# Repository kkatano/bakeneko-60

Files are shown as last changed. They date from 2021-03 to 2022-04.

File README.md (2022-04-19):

# Bakeneko 60 V3

A simple 60% keyboard for DIYers. This project is a special homage to TGR x Singa UNIKORN 60 and OTD 356 Mini. See also the [introduction video](https://youtu.be/8zyG34YU3BY).

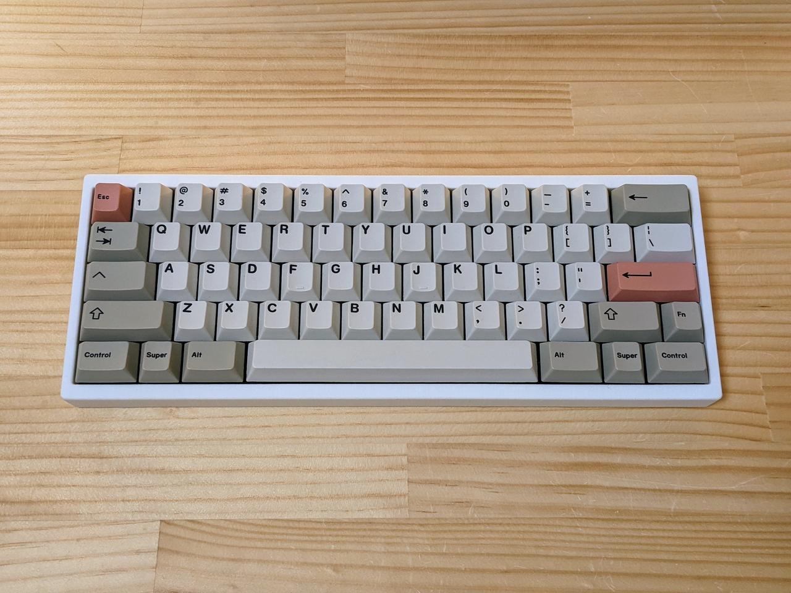
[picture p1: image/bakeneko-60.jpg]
Bakeneko 60


## Features

- Single piece tray case
- O-ring gasket mount (Friction fit)
- [Unified Daughterboard](https://github.com/ai03-2725/Unified-Daughterboard)
- QMK firmware and VIA
- Compatible with common 60% plates
- PCB designed with KiCAD 5.1.4

## Layouts

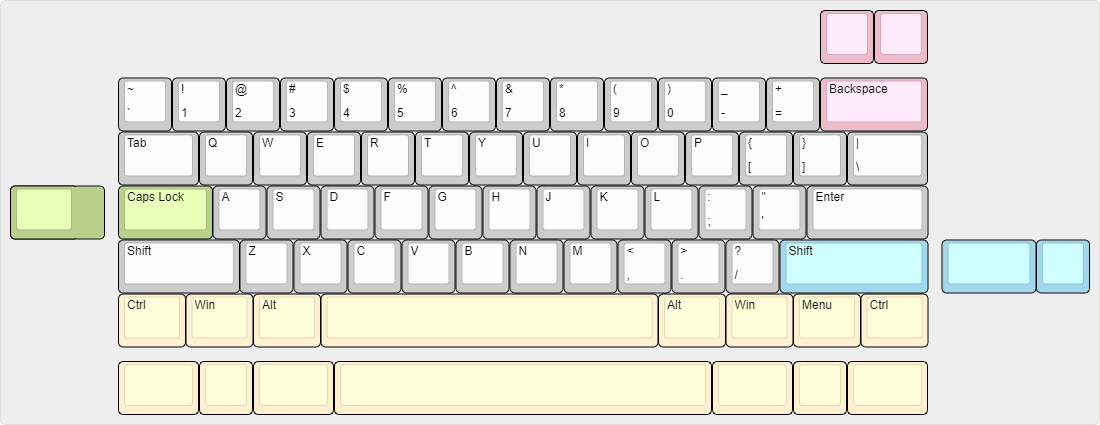
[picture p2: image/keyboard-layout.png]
Bakeneko 60 layouts


## Specs

- Dimensions: 295 x 110 x 30mm
- Front height: 18.5mm
- Home row height: 31mm(with GMK keycaps and bumpons)
- Typing angle: 6 degree
- Weight:
  - PLA Case: 370g
  - Aluminum Case: 700g
- O-ring gasket: VMQ-50(Silicone 50 duro) AS568-262

## Notes

- Old files (v1) are no longer available. See [geekhack post](https://geekhack.org/index.php?topic=107316.msg2974824#msg2974824) for the context
- The use of old (v1) mounting posts is prohibited
- All files are to be used at your own risk
- As for stabilizers, only PCB snap ins are supported
- This open source version is not compatible with CannonKeys Bakeneko

## Resources

- Documents: https://drive.google.com/drive/folders/1tddSihOS8Pgf1lTQOjHohYCl8efxXIeH
  - Parts guide and other useful information
  - Will be added and updated as needed
- Discord: https://discord.gg/fMY96TeEwV
  - Have fun with community members
  - Talk about Bakeneko builds and mods, and share your works
  - You can also contact me from there

## Special thanks to

- **Elaine** for [Unikorn](https://geekhack.org/index.php?topic=98587.50). Allowed me to publish the Unikorn-inspired case as open source and encouraged me
- Of course, I also show my respect and gratitude to **yuktsi**
- **coarse** for PCB review and kind support. His great work has refined the PCB well

## Also I should mention

- **OTD** for 356 Mini. Origin of O-ring gasket mount style
- **Evy** for [Plain60 series](https://github.com/evyd13/plain60-c). I used it as a reference for my PCB design. They also answered my miscellaneous questions
- **ai03** for [MX_Alps_Hybrid](https://github.com/ai03-2725/MX_Alps_Hybrid). Also got a lot of help from his discord server
- **overset** for [JP01](https://github.com/overset/JP01). The idea of publishing the case design on Onshape. After seeing their great work I switched from fusion360 to Onshape
- **Rhuk** gave me a lot of advice on keyboard design and manufacturing
- **Maker Keyboards** suggested adding a plate cutout to remove the PCB using a keycap puller
- And many community members for giving me advice and feedback, thanks!

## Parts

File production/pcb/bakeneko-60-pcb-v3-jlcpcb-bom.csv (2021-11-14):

Designator | Comment | Footprint | LCSC Part #
C1 C2 C3 | 0.1u | Capacitor_SMD:C_0805_2012Metric | C49678
C4 | 10u | Capacitor_SMD:C_0805_2012Metric | C15850
C5 C7 | 22p | Capacitor_SMD:C_0805_2012Metric | C1804
C6 | 1u | Capacitor_SMD:C_0805_2012Metric | C28323
D63 D62 D61 D60 D59 D58 D57 D56 D55 D54 D53 D52 D51 D50 D49 D48 D47 D46 D45 D44 D43 D42 D41 D40 D39 D38 D37 D36 D35 D34 D33 D32 D31 D30 D29 D28 D27 D26 D25 D24 D23 D22 D21 D20 D19 D18 D17 D16 D15 D14 D13 D12 D11 D10 D9 D8 D7 D6 D5 D4 D3 D2 D1 | 1N4148 | Diode_SMD:D_SOD-123 | C81598
F1 | 500mA | Fuse:Fuse_1206_3216Metric | C70076
J1 | JST SH 4-pin | Connector_JST:JST_SH_SM04B-SRSS-TB_1x04-1MP_P1.00mm_Horizontal | C160404
R1 R2 | 22 | Resistor_SMD:R_0805_2012Metric | C17561
R4 R3 | 10k | Resistor_SMD:R_0805_2012Metric | C17414
SW1 | Reset | Button_Switch_SMD:SW_SPST_TL3342 | C318884
U1 | SRV05-4 | Package_TO_SOT_SMD:SOT-23-6 | C85364
U2 | ATmega32U4-AU | Package_QFP:TQFP-44_10x10mm_P0.8mm | C44854
Y1 | 16MHz | Crystal:Crystal_SMD_3225-4Pin_3.2x2.5mm | C13738

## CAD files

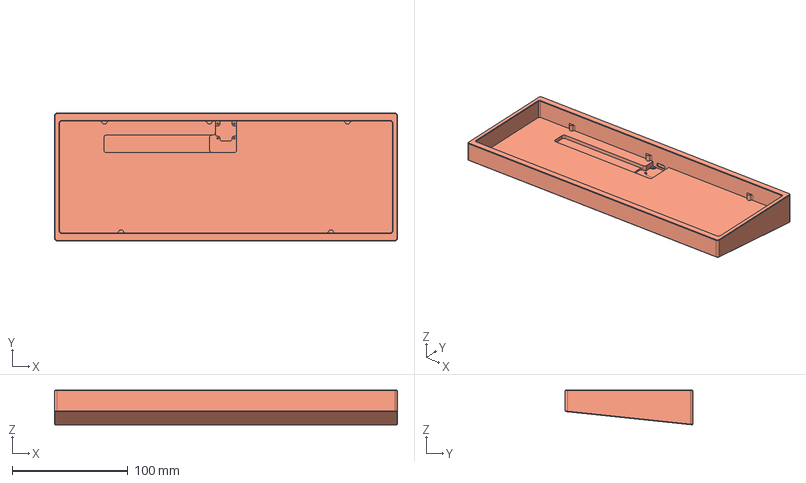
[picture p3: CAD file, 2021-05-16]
case-pla/bakeneko-60-pla.step
295.7 x 110.2 x 30.0 mm

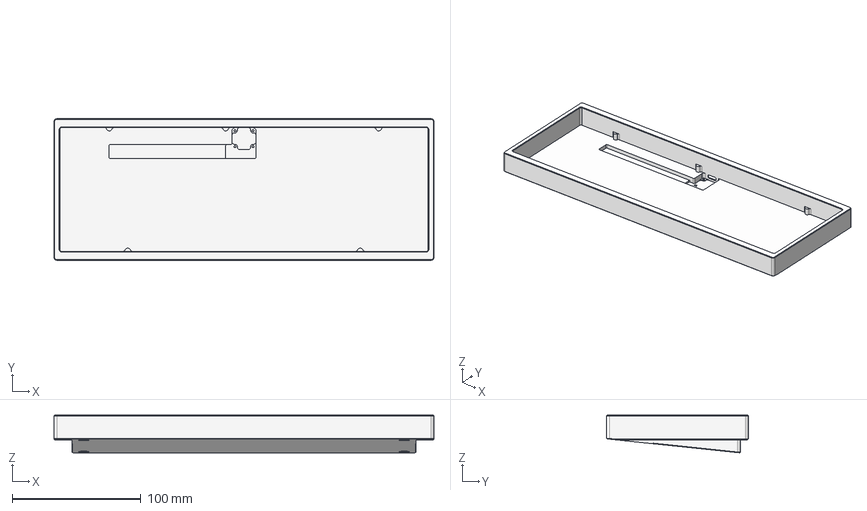
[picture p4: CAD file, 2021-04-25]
case/aluminum/bakeneko-60-case.step
295.7 x 110.2 x 29.4 mm

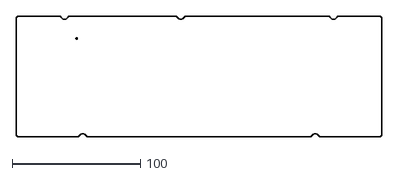
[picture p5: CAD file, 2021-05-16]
pcb/pcb-outline.dxf
284.7 x 94.2

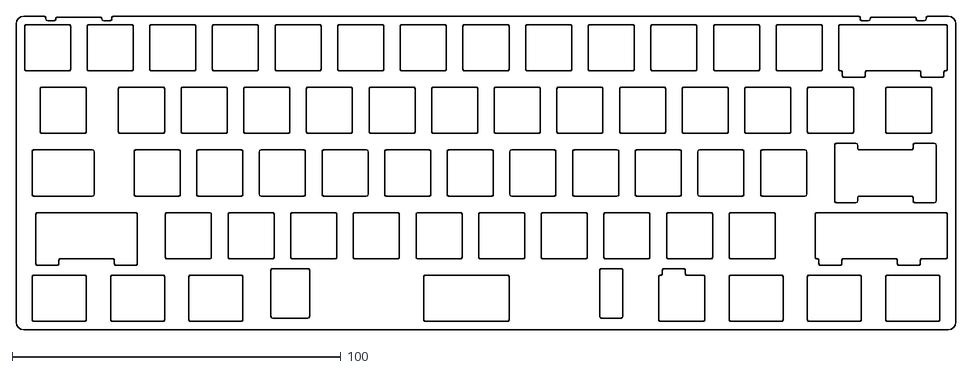
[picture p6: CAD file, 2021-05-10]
plate/bakeneko-60-plate.dxf
285.8 x 95.3

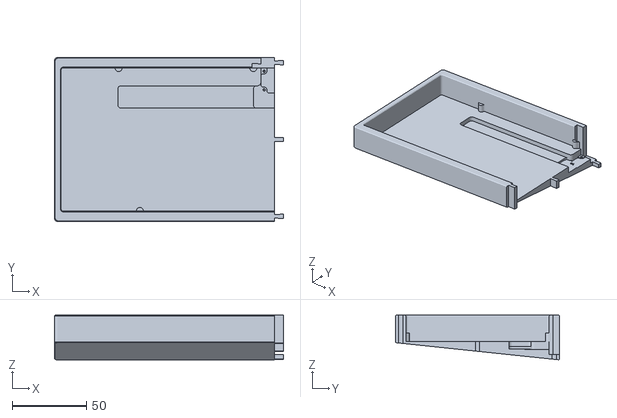
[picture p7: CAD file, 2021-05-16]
case-pla/bakeneko-60-pla-split-left.stl
153.9 x 110.2 x 30.0

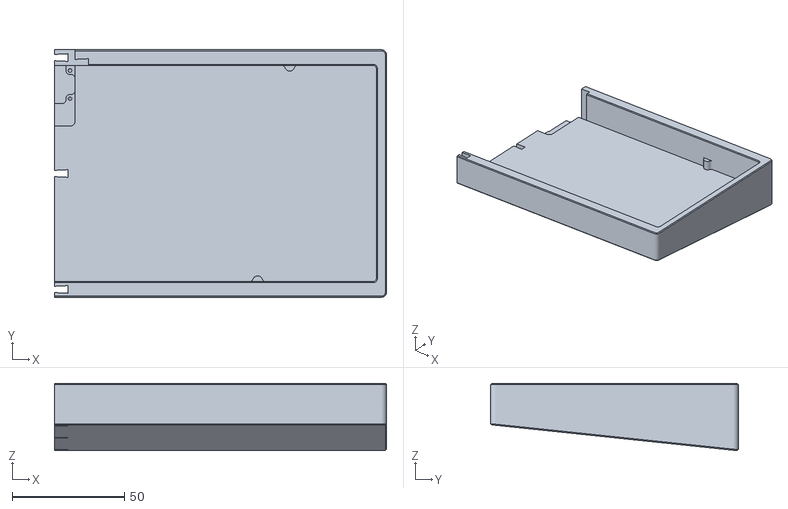
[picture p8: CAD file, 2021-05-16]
case-pla/bakeneko-60-pla-split-right.stl
147.8 x 110.2 x 30.0

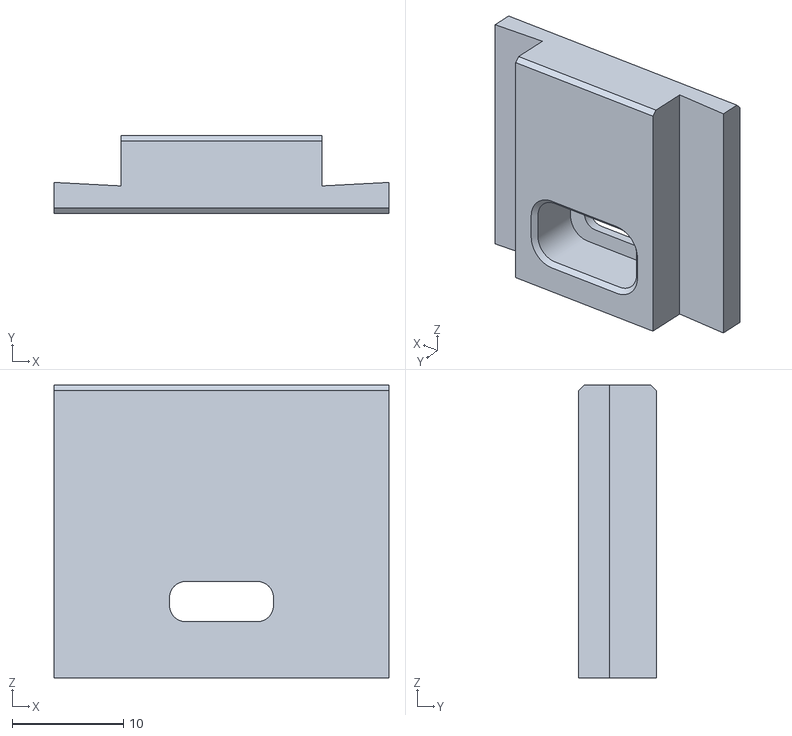
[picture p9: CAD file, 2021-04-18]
case-pla/bakeneko-60-pla-split-usb.stl
30.1 x 7.00 x 26.3

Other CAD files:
case/bakeneko-60-case.step

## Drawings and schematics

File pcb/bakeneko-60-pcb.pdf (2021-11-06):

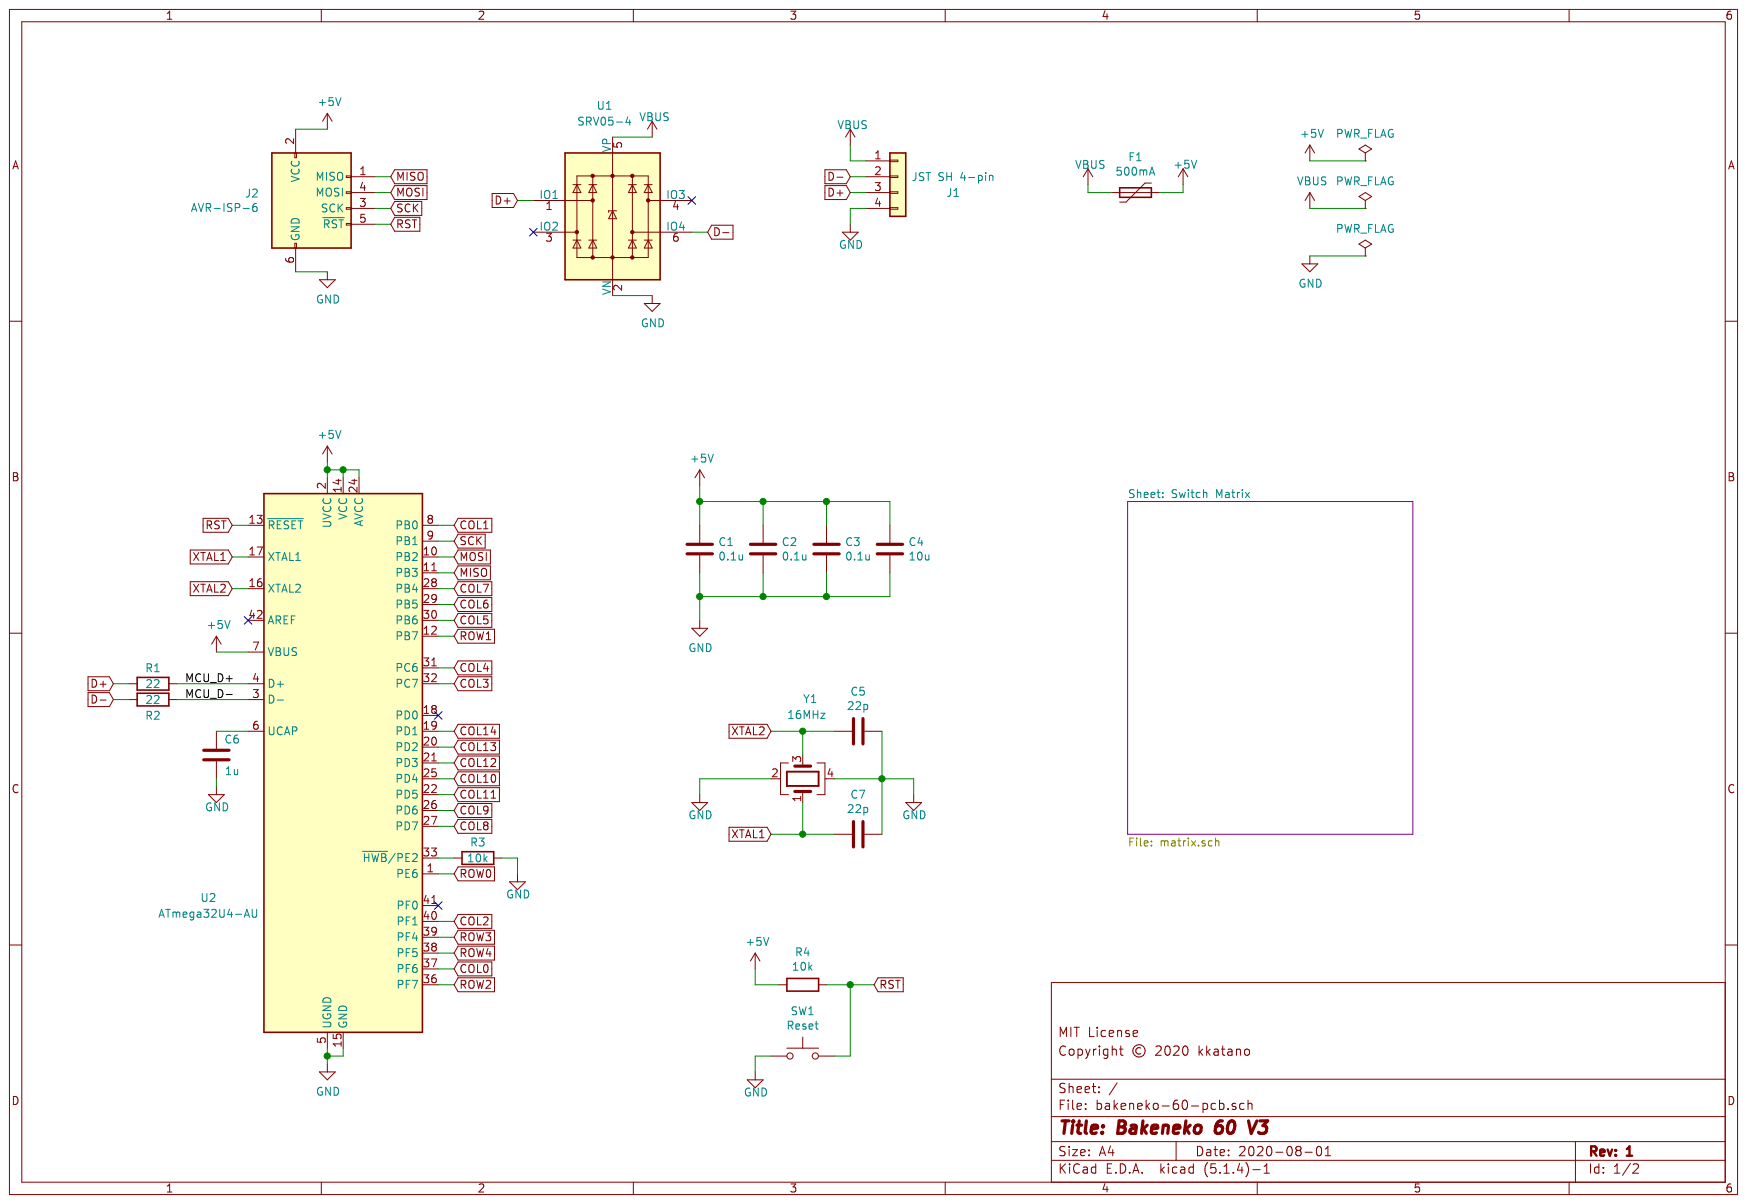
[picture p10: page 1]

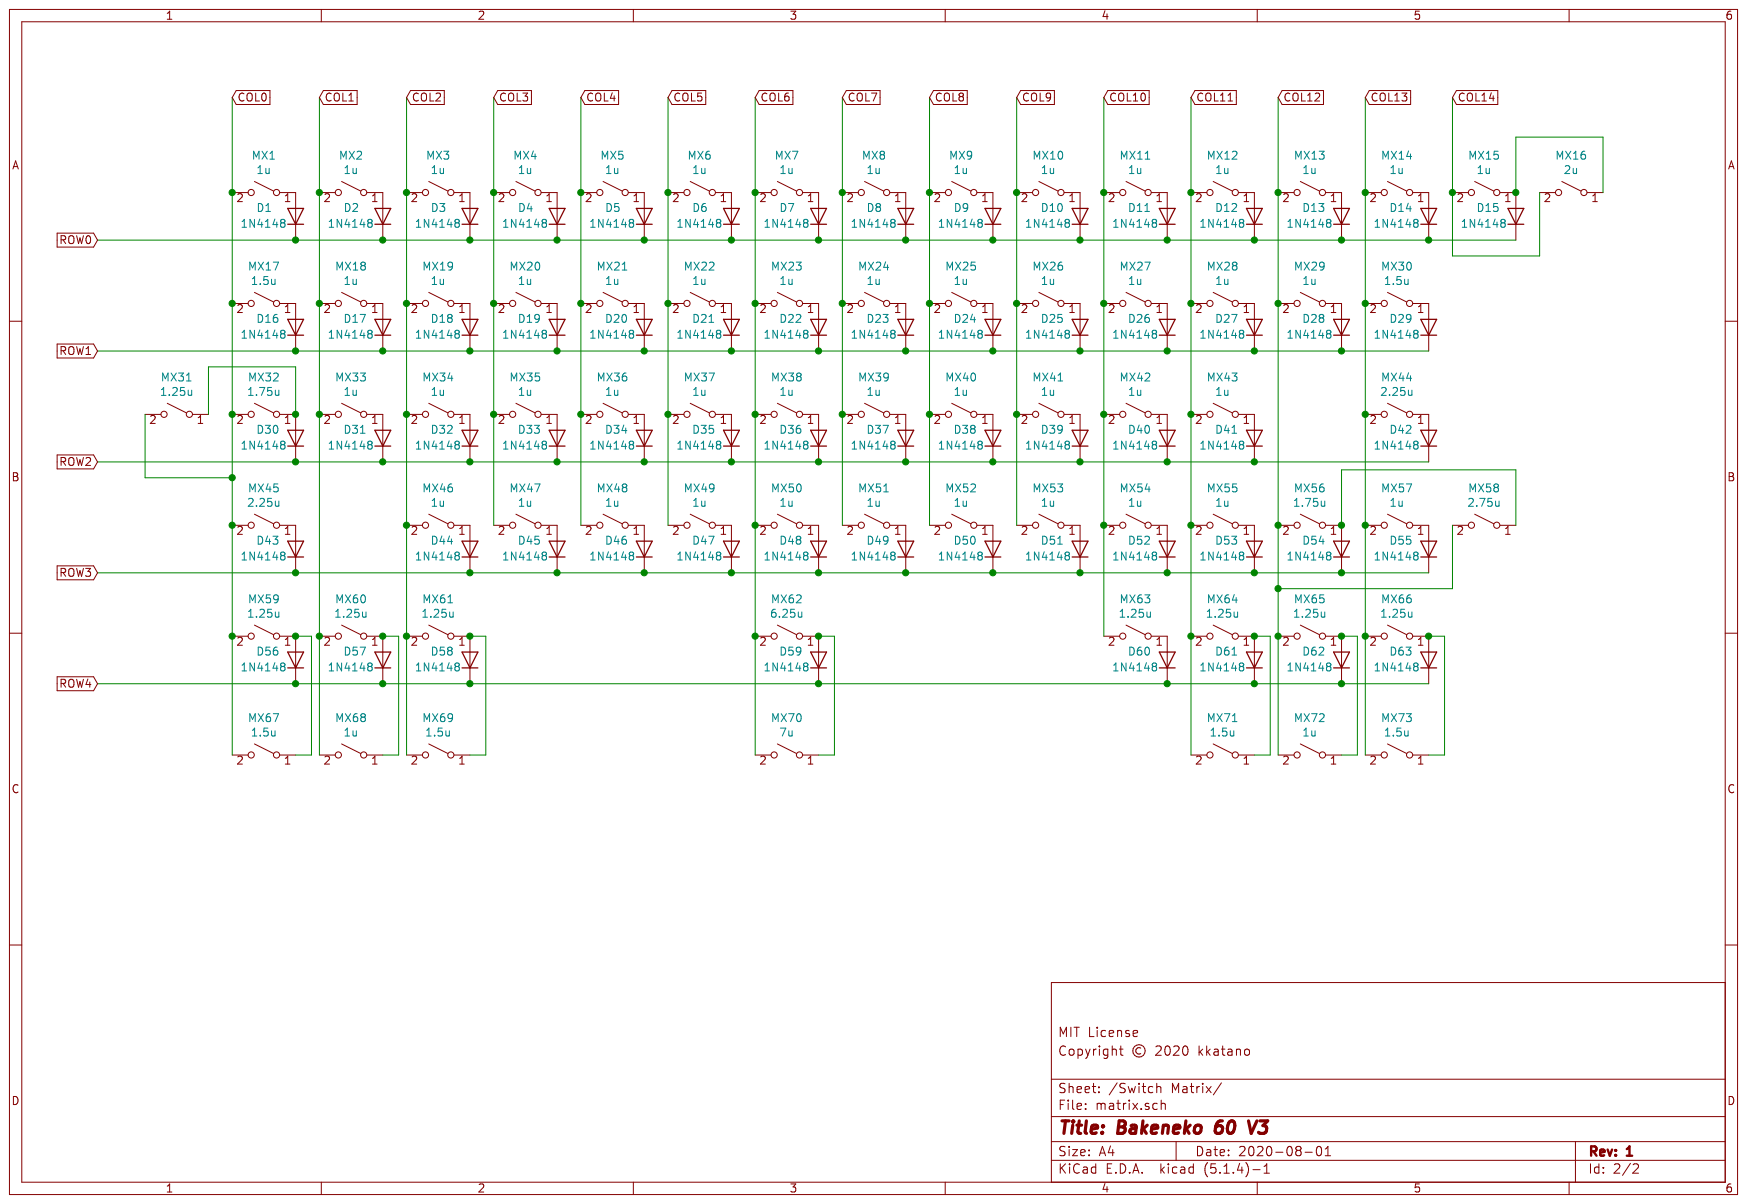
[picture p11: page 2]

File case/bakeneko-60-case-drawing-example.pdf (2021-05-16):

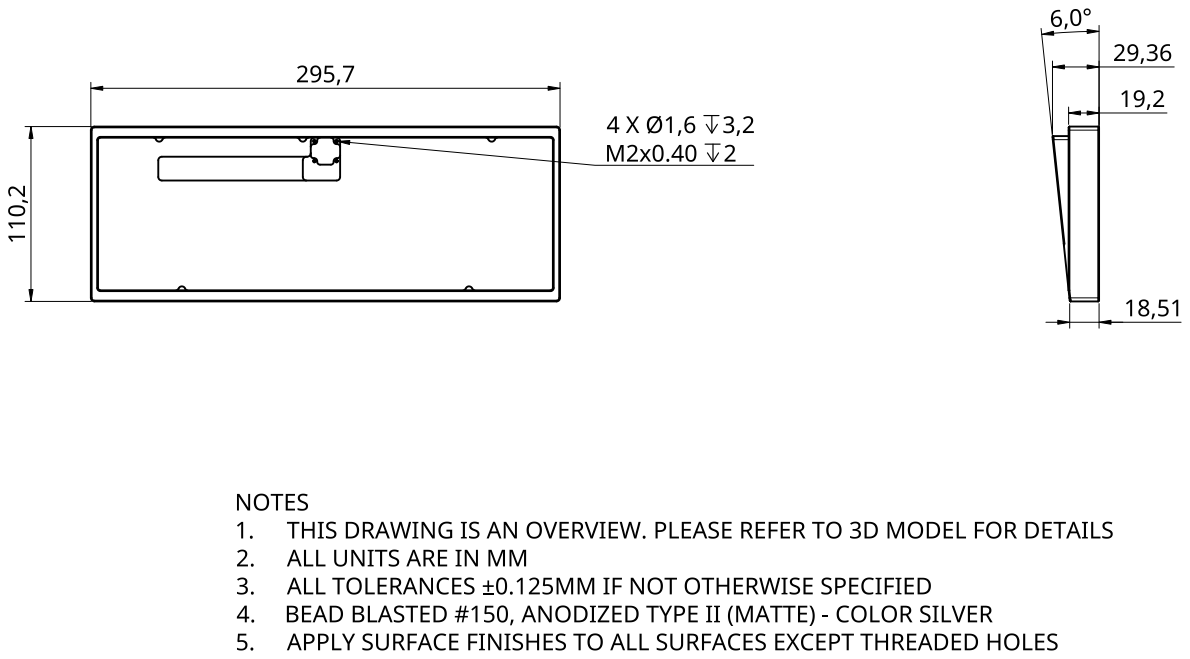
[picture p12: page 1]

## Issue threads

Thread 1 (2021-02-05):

Hot-swap PCB?

samiyuru, 2021-02-05:
Are there any hot-swap PCBs compatible with the case?

kkatano, 2021-02-05:
No, there is no compatible hot-swap PCB at this time

samiyuru, 2021-02-06:
Any chance this will work? https://keycult.com/collections/accessories/products/wt60-a-pcb-60

kkatano, 2021-02-06:
It will not fit because the JST connector is in a different position.

Closed 2021-02-06.

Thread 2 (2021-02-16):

Would flex cuts in the PCB be possible? Similar to the Plain60-flex

Dallagen2, 2021-02-16:
would take significant trace rerouting so i'd understand if the time isn't worth it though

kkatano, 2021-02-18:
I tried it on an earlier version of the prototype, but I prefer the feel of the PCB without the cutouts. In the future I may make a PCB with flex cuts, but for now I have no plans to do so.

Closed 2021-03-03.

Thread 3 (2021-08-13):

screw in stabilizer support?

zayn2005, 2021-08-13:
Hey kkatano, does the bakeneko v3 support screw in stabilizers as opposed to previous versions?

kkatano, 2021-08-17:
@zayn2005 Sorry for the late reply, v3 doesn't support screw ins either

Closed 2021-08-17.

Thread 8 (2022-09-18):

Unable to load in VIA

Endur3D, 2022-09-18:
Assembled the keyboard today, tried opening it in VIA on two separate computers (Windows and linux) and it did not work - it was just stuck on "searching for device". Works great with my other keyboards.

I tried flashing it through QMK Toolbox, but now the keyboard has become entirely unresponsive.
Used the reset button and tried again with different .hex file and different keymapping but it doesn't work.

How can I fix this?

kkatano, 2022-09-18:
This is not the place to support via or qmk. However, someone on my discord may be able to help. In that case, you would need to provide a bit more context. (what you tried, how you got the firmware, etc.)

Closed 2022-09-18.

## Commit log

2021-02-13 Update board outline
    [bakeneko-60-pcb.kicad_pcb, pcb-outline.dxf]
2021-02-13 Update version string
    [bakeneko-60-pcb.kicad_pcb]
2021-02-13 Remove ISP
    [bakeneko-60-pcb.kicad_pcb, bakeneko-60-pcb.sch]
2021-02-13 Change JST port position
    [bakeneko-60-pcb.kicad_pcb]
2021-02-13 Create FR4 plate project
    [bakeneko-60-fr4-plate.kicad_pcb, bakeneko-60-fr4-plate.sch]
2021-02-13 Update metadata
    [bakeneko-60-pcb.sch]
2021-02-13 Remove old files
    [bakeneko-60.step]
2021-02-13 Update PCB readme
2021-02-14 Add PLA case
    [bakeneko-60-left.stl, bakeneko-60-right.stl, bakeneko-60-usb.stl]
2021-02-14 Add Weight outline for laser cutting
    [weight.dxf]
2021-02-14 Add aluminum case
    [bakeneko-60-case.step, bakeneko-60-weight.step]
2021-02-17 Update PLA case
    [bakeneko-60-left.stl, bakeneko-60-right.stl, bakeneko-60-usb.stl]
2021-02-21 Update aluminum case
    [bakeneko-60-case.step, bakeneko-60-weight.step]
2021-03-06 Update plate
    [bakeneko-60-plate.dxf, layout-ansi.dxf, layout-tsangan-steppedcaps-reversedenter.dxf]
2021-04-18 Update case
    [bakeneko-60-case.step, bakeneko-60-weight.step]
2021-04-18 Update pcb image
2021-04-25 Remove plate dxf
    [layout-ansi.dxf, layout-tsangan-steppedcaps-reversedenter.dxf]
2021-04-25 Update PCB
    [bakeneko-60-pcb.kicad_pcb, pcb-outline.dxf]
2021-06-20 Add production files
    [bakeneko-60-pcb-v3-jlcpcb-bom.csv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]
2021-11-06 Add comment
    [bakeneko-60-pcb.sch, matrix.sch]
2021-11-14 Update production files
    [bakeneko-60-pcb-v3-jlcpcb-bom.csv]
